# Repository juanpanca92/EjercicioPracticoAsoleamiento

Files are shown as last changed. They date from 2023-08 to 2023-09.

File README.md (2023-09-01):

# EjercicioPracticoAsoleamiento
Ejercicio académico de exploración sobre el asoleamiento en arquitectura a partir de un modelo físico que recrea un heliodon y permite realizar estudios de asoleamiento para diferentes latitudes.

Los documentos son libres y suceptibles de mejora.
Es una propouesta metodológica para el aprendizaje de la mecánica solar y su relación con el ejercicio proytectual en arquitectura.

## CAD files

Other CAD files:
Bioclimática_Despiece Modelo Casa Poli.dwg
Bioclimática_Despiece Heliodon.dwg

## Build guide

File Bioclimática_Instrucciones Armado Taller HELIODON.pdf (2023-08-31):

# Taller Heliodón

## Bioclimática

Instrucciones de armado

Maqueta de estudio Casa Poli | Heliodón
https://www.linkedin.com/in/pan92/ | Juan Paniagua Carvajal

## Plataforma

# Heliodón 1

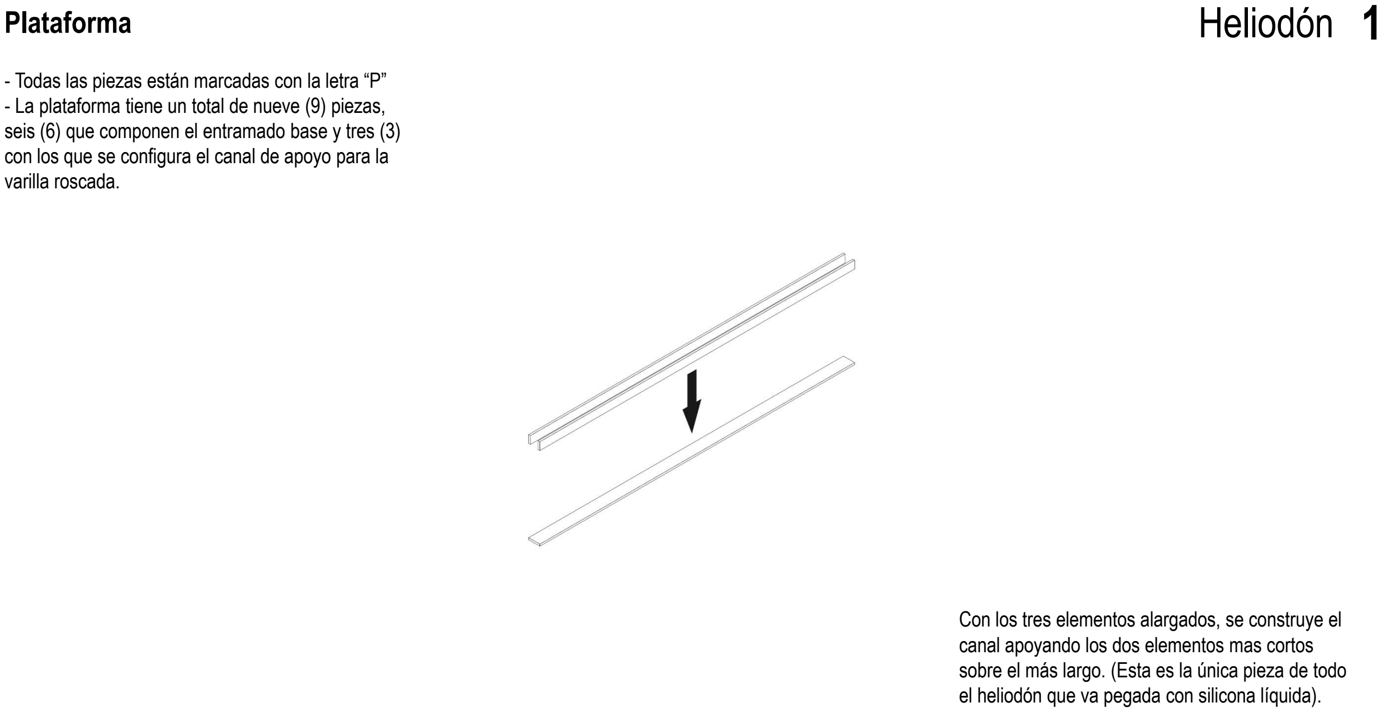
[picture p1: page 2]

- Todas las piezas están marcadas con la letra “P”
- La plataforma tiene un total de nueve (9) piezas, seis (6) que componen el entramado base y tres (3) con los que se configura el canal de apoyo para la varilla roscada.

Con los tres elementos alargados, se construye el canal apoyando los dos elementos mas cortos sobre el más largo. (Esta es la única pieza de todo el heliodón que va pegada con silicona líquida).

## Plataforma

# Heliodón 2

- Todas las piezas están marcadas con la letra “P”
- La plataforma tiene un total de nueve (9) piezas, seis (6) que componen el entramado base y tres (3) con los que se configura el canal de apoyo para la varilla roscada.

El elemento debe quedar de esta forma

## Plataforma

# Heliodón 3

- Todas las piezas están marcadas con la letra “P”
- La plataforma tiene un total de nueve (9) piezas, seis (6) que componen el entramado base y tres (3) con los que se configura el canal de apoyo para la varilla roscada.

Las piezas se ensamblan de forma machimbrada como lo indica la imagen.
Hay tres de las piezas que tienen un canal en la parte superior; sobre este canal se apoya el elemento construido en el paso anterior

Plataforma | 4

# Heliodón

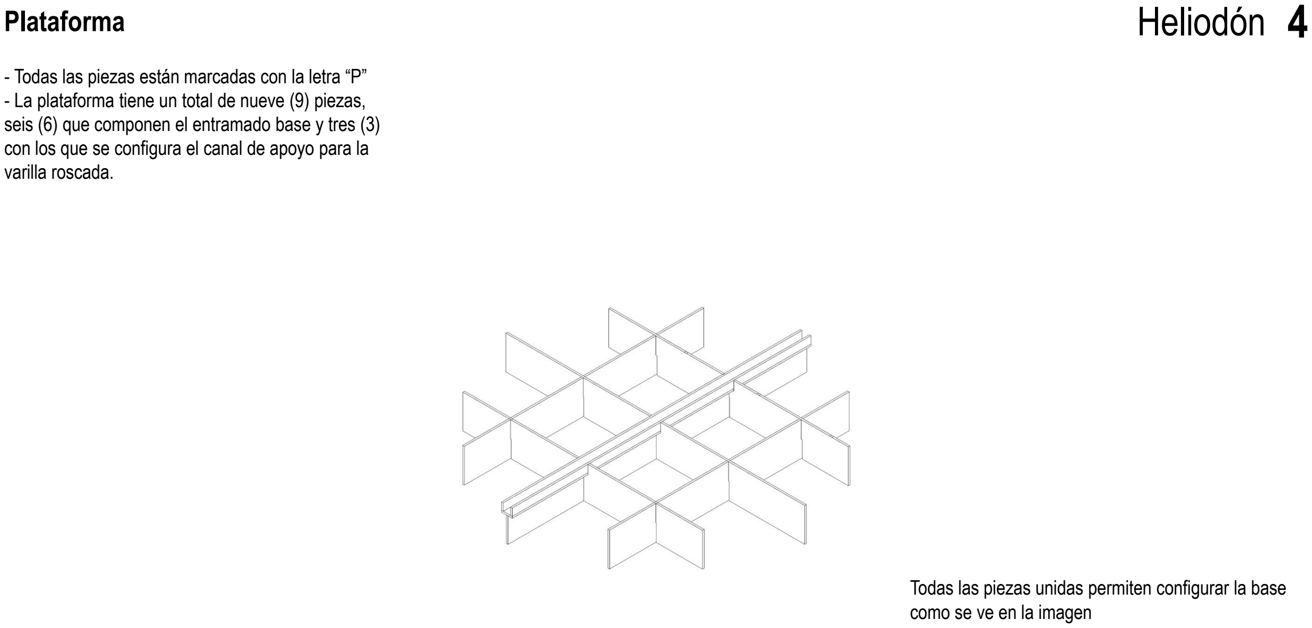
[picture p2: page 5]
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

Todas las piezas unidas permiten configurar la base como se ve en la imagen

Plataforma | 5

# Heliodón

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

Se coloca la varilla roscada de 70cm de largo sobre la plataforma

Plataforma | 6

# Heliodón

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

Por el momento la varilla solo se apoya sobre la plataforma.

Base | 7

# Heliodón

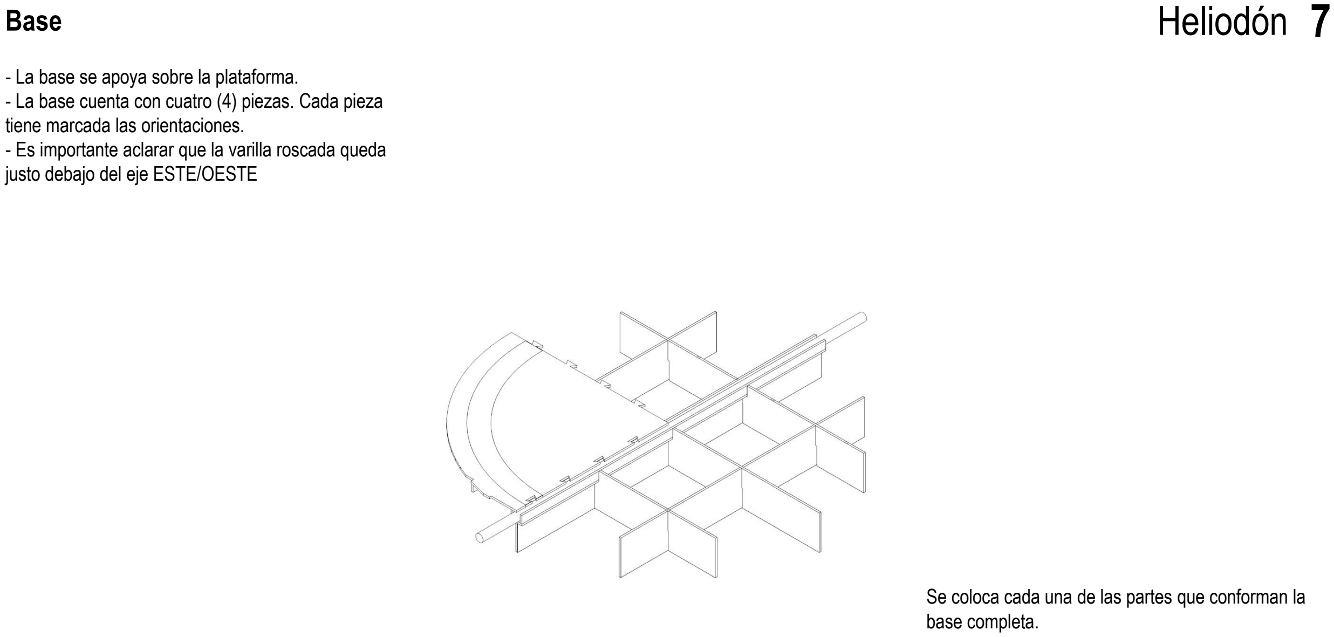
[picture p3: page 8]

- La base se apoya sobre la plataforma.
- La base cuenta con cuatro (4) piezas. Cada pieza tiene marcada las orientaciones.
- Es importante aclarar que la varilla roscada queda justo debajo del eje ESTE/OESTE

Se coloca cada una de las partes que conforman la base completa.

Base | 8

# Heliodón

- La base se apoya sobre la plataforma.
- La base cuenta con cuatro (4) piezas. Cada pieza tiene marcada las orientaciones.
- Es importante aclarar que la varilla roscada queda justo debajo del eje ESTE/OESTE

Se coloca cada una de las partes que conforman la base completa.

Base | 9

# Heliodón

- La base se apoya sobre la plataforma.
- La base cuenta con cuatro (4) piezas. Cada pieza tiene marcada las orientaciones.
- Es importante aclarar que la varilla roscada queda justo debajo del eje ESTE/OESTE

Se coloca cada una de las partes que conforman la base completa.

Base | 10

# Heliodón

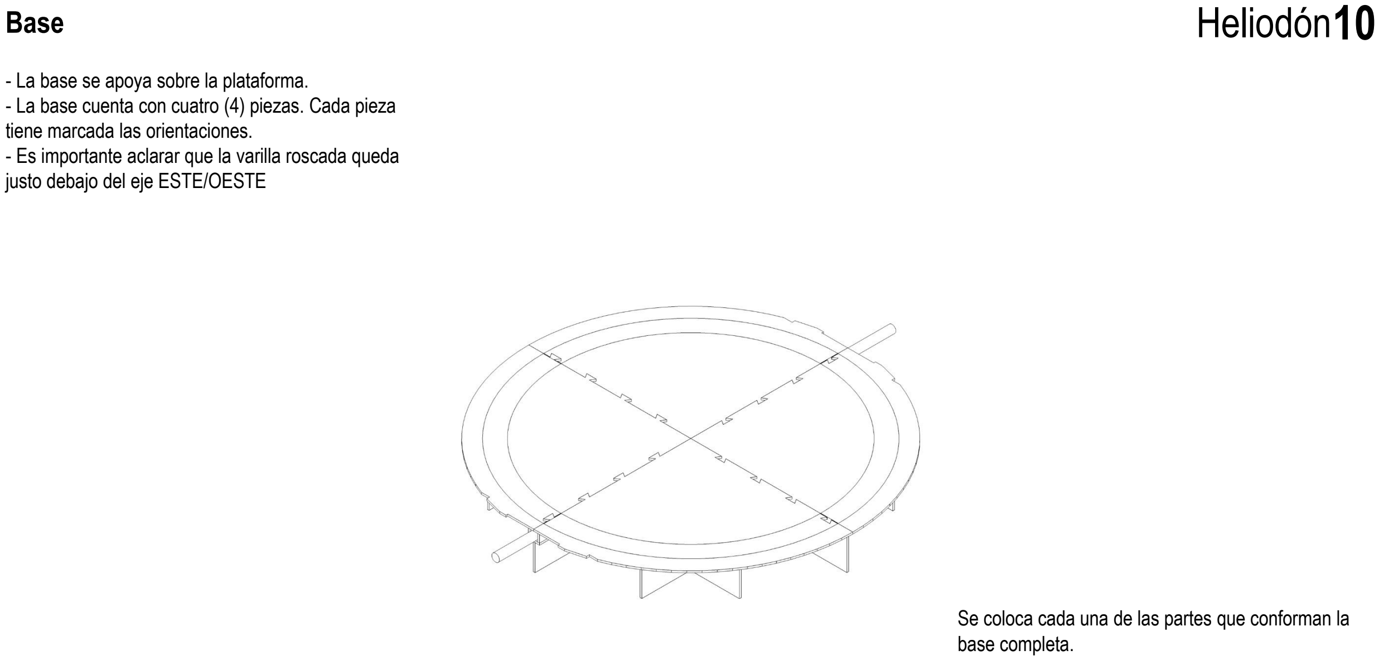
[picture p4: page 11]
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

Se coloca cada una de las partes que conforman la base completa.

Guías latitud | 11

# Heliodón

- Teniendo la varilla como guía y la base ubicada, los dos discos guías de la latitud encajan en los extremos ESTE y OESTE del heliodón.
- El encaje de estas piezas, asegura tanto la plataforma como la base.
- NOTA: No se deben poner las tuercas aún.

Cómo se indica en la imagen, los discos encajan en la varilla. La línea guía marcada en cada disco debe ir hacía el exterior del heliodón y ubicada en la parte superior del disco.

Guías latitud | 12

# Heliodón

- Teniendo la varilla como guía y la base ubicada, los dos discos guías de la latitud encajan en los extremos ESTE y OESTE del heliodón.
- El encaje de estas piezas, asegura tanto la plataforma como la base.
- NOTA: No se deben poner las tuercas aún.

Una vez encajadas las piezas, el heliodón se debe ver de esta manera

Soportes bóveda | 13
- Son dos soportes en total, cada uno esta marcado
en sus diferentes piezas como “A” y “B”.
- Cada uno de los soportes se construye con un total de cinco (5) piezas.
- De las piezas que se resaltan en rojo, hay una por soporte que cuenta con tres (3) letras adicionales marcadas: “J” – “S” – “D”. Esta pieza debe ir en la parte superior
- Estas letras corresponden a los meses de las fechas representativas del calendario solar, y son la guía para los elementos de la bóveda.
- Cada uno de los soportes se debe ubicar en el heliodón siguiendo la lógica de la mecánica solar. La letra “J” correspondiente al mes de Junio debe ir hacía el norte.

Las piezas encajan entre ellas como se indica en la imagen.

# Heliodón

Soportes bóveda | 14

Una vez se tenga el soporte armando es encajado a través de la varilla roscada en el resto del heliodón.
NOTA: Se recuerda la importancia de ubicar el soporte según las letras guías y el norte del heliodón.
- Son dos soportes en total, cada uno esta marcado en sus diferentes piezas como “A” y “B”.
- Cada uno de los soportes se construye con un total de cinco (5) piezas.
- De las piezas que se resaltan en rojo, hay una por soporte que cuenta con tres (3) letras adicionales marcadas: “J” – “S” – “D”. Esta pieza debe ir en la parte superior
- Estas letras corresponden a los meses de las fechas representativas del calendario solar, y son la guía para los elementos de la bóveda.
- Cada uno de los soportes se debe ubicar en el heliodón siguiendo la lógica de la mecánica solar. La letra “J” correspondiente al mes de Junio debe ir hacía el norte.

# Heliodón

Soportes bóveda | 15

# Heliodón

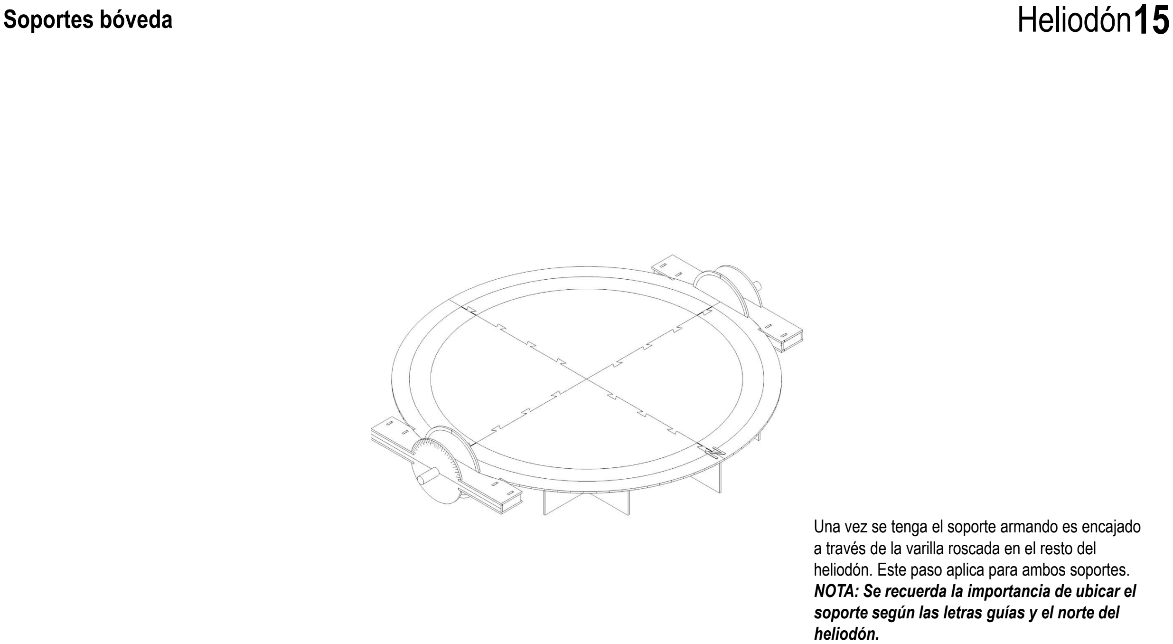
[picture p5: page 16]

Una vez se tenga el soporte armando es encajado a través de la varilla roscada en el resto del heliodón. Este paso aplica para ambos soportes. NOTA: Se recuerda la importancia de ubicar el soporte según las letras guías y el norte del heliodón.

Ajuste soportes | 16

# Heliodón

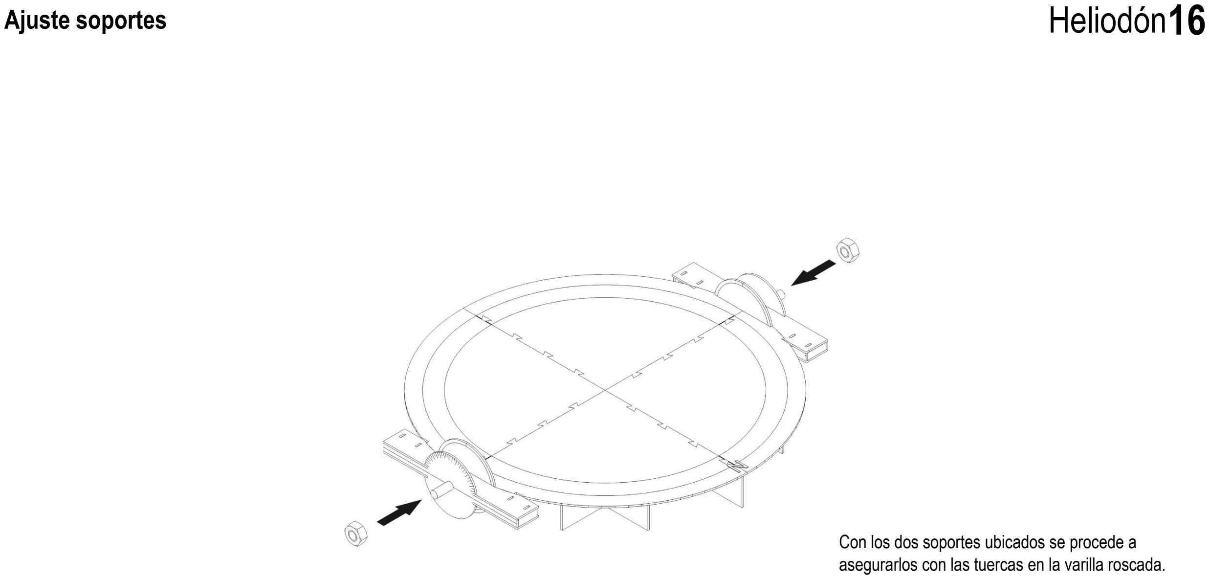
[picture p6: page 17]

Con los dos soportes ubicados se procede a asegurarlos con las tuercas en la varilla roscada.

Disposición bóveda | 17

# Heliodón

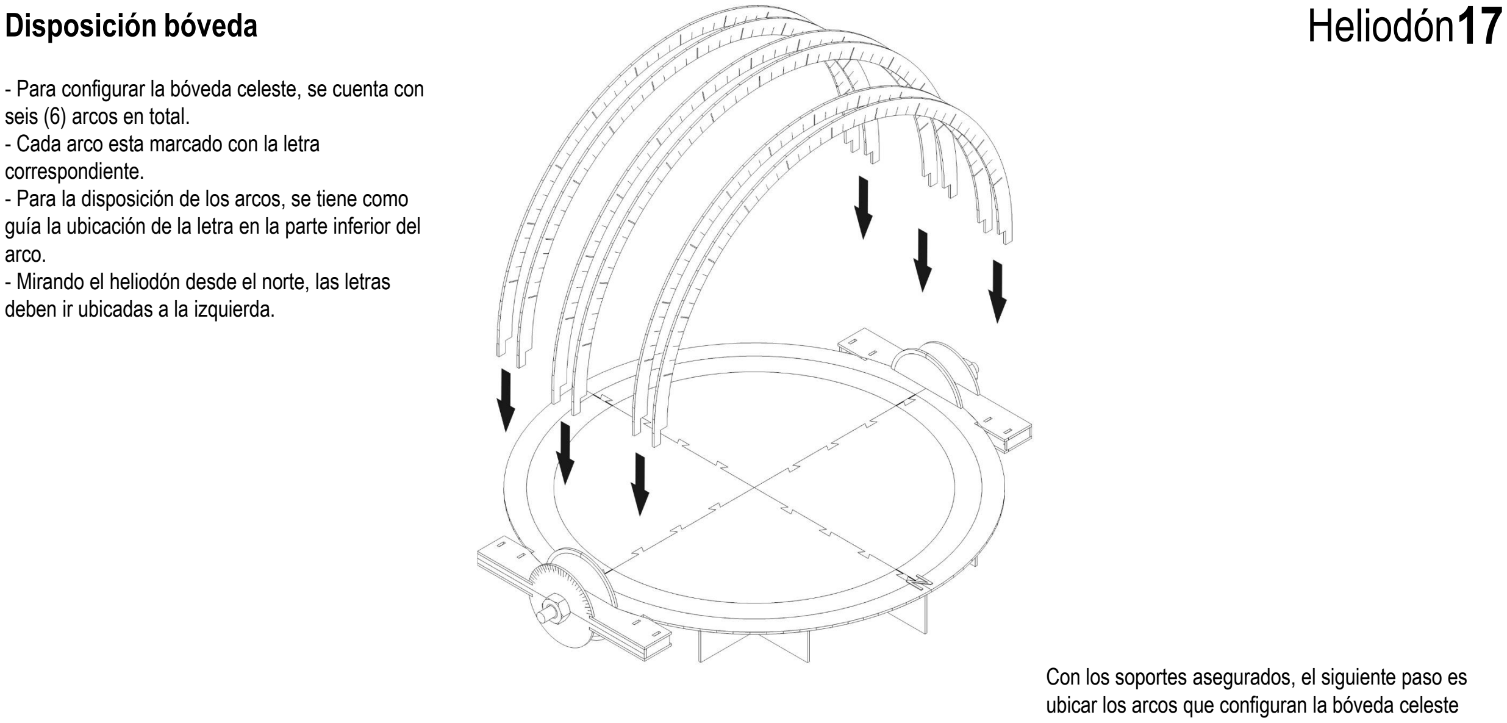
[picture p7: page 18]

Con los soportes asegurados, el siguiente paso es ubicar los arcos que configuran la bóveda celeste

- Para configurar la bóveda celeste, se cuenta con seis (6) arcos en total.
- Cada arco esta marcado con la letra correspondiente.
- Para la disposición de los arcos, se tiene como guía la ubicación de la letra en la parte inferior del arco.
- Mirando el heliodón desde el norte, las letras deben ir ubicadas a la izquierda.

Disposición bóveda | 18

# Heliodón

Al ubicar cada uno de los arcos en su ranura correspondiente, el heliodón se debe ver como en la imagen.

Soportes luz/sol – Guías horas | 19

# Heliodón

Los soportes de luz número 1 y 3 están constituidos por seis (6 piezas).
El soporte de luz número 2 esta constituido por cinco (5) piezas .
Cada soporte de luz encaja de forma machimbrada.
- El heliodón cuenta con tres (3) de estos soportes, los cuales se disponen en las tres parejas de arcos correspondientes a los diferentes meses.
- Los soportes de luz están marcados con los números 1,2 y 3. El número 2 corresponde a la letra “S”, los números 1 y 3 a las letras “J” y “D”.

Soportes luz/sol – Guías horas | 20

# Heliodón

Los soportes de luz número 1 y 3 están constituidos por seis (6 piezas).
El soporte de luz número 2 esta constituido por cinco (5) piezas .
Cada soporte de luz encaja de forma machimbrada.
- El heliodón cuenta con tres (3) de estos soportes, los cuales se disponen en las tres parejas de arcos correspondientes a los diferentes meses.
- Los soportes de luz están marcados con los números 1,2 y 3. El número 2 corresponde a la letra “S”, los números 1 y 3 a las letras “J” y “D”.

Soportes luz/sol – Guías horas | 21

# Heliodón

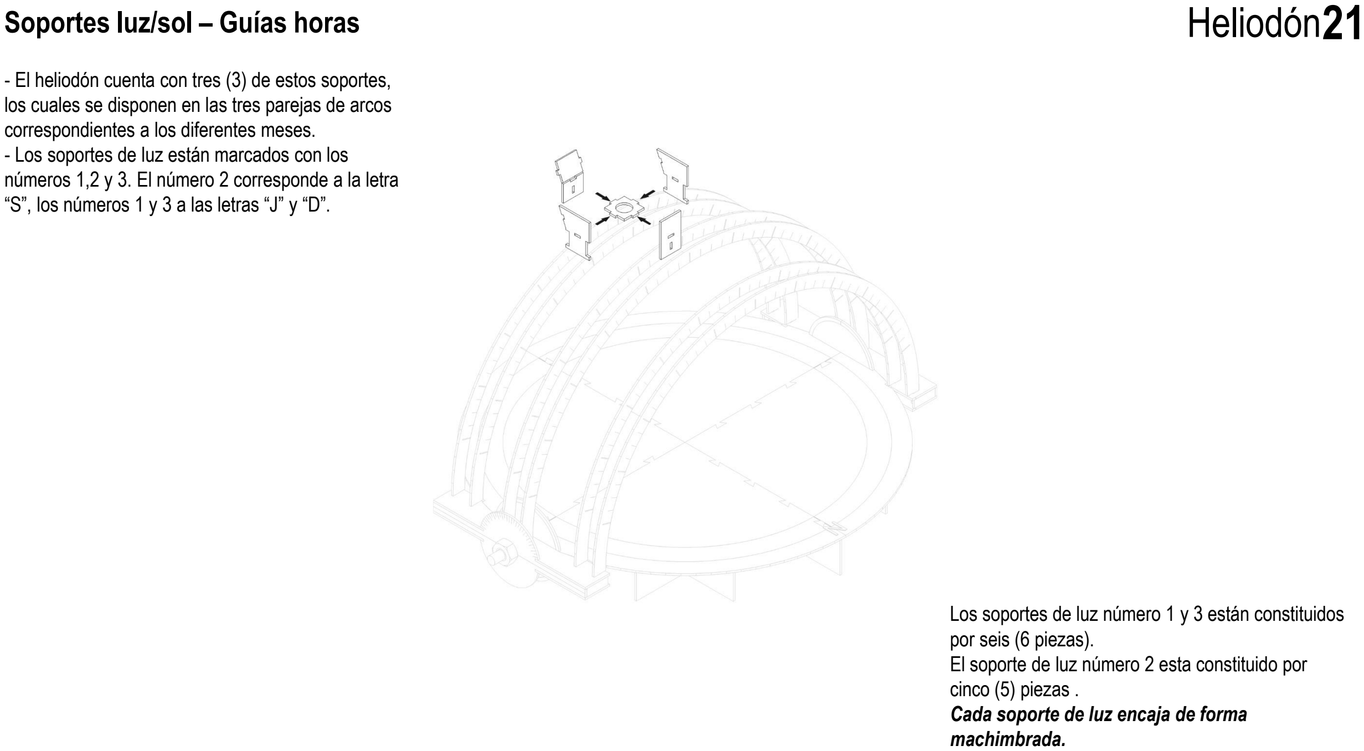
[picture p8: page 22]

Los soportes de luz número 1 y 3 están constituidos por seis (6 piezas).
El soporte de luz número 2 esta constituido por cinco (5) piezas .
Cada soporte de luz encaja de forma machimbrada.
- El heliodón cuenta con tres (3) de estos soportes, los cuales se disponen en las tres parejas de arcos correspondientes a los diferentes meses.
- Los soportes de luz están marcados con los números 1,2 y 3. El número 2 corresponde a la letra “S”, los números 1 y 3 a las letras “J” y “D”.

Heliodón armado | 22

# Heliodón

Una vez ubicados los soportes de luz, el heliodón ha sido construido y ensamblado en su totalidad, se debe ver como en la imagen.

- Con todas las piezas ensambladas el heliodón esta completo; el siguiente paso es ubicar la linterna en el soporte de luz según la fecha y hora que se quiere evaluar.

Organización fichas | 23 - | El despiece entregado contiene una

numeración para cada una de las fichas, se
recomienda despegar cuidadosamente la cinta de enmascarar e identificar las fichas que tienen un número o una letra (en el caso del terreno). Hay fichas que se repiten hasta

3
veces es importante agruparlas todas.

NOTA: La maqueta de estudio se compone de tres materiales, cartón paja para el terreno y la base, cartón caja 2mm para muros interiores y fachadas y cartón caja 4mm para recrear los volúmenes perimetrales. (las siguientes imágenes muestran número por número dónde va la ficha)

# Maqueta de estudio

Armado | 24

# Maqueta de estudio

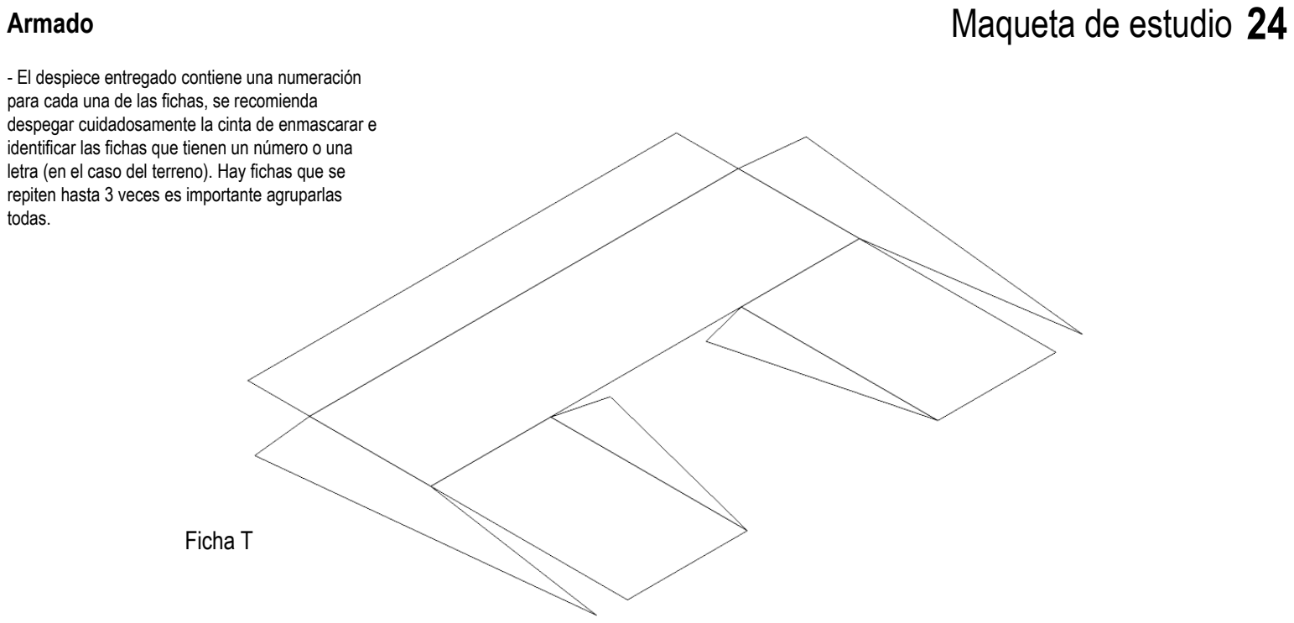
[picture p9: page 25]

- El despiece entregado contiene una numeración para cada una de las fichas, se recomienda despegar cuidadosamente la cinta de enmascarar e identificar las fichas que tienen un número o una letra (en el caso del terreno). Hay fichas que se repiten hasta 3 veces es importante agruparlas todas.

## Ficha T

Armado | 25

# Maqueta de estudio

- El despiece entregado contiene una numeración para cada una de las fichas, se recomienda despegar cuidadosamente la cinta de enmascarar e identificar las fichas que tienen un número o una letra (en el caso del terreno). Hay fichas que se repiten hasta 3 veces es importante agruparlas todas.

## Ficha T

Armado | Maqueta de estudio 26

## Ficha 1 y 2

Armado | Maqueta de estudio 27

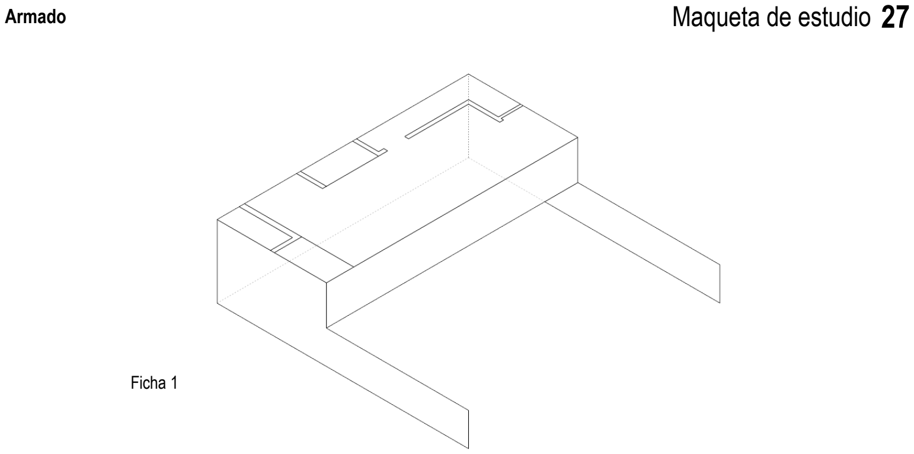
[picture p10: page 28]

## Ficha 1

Armado | Maqueta de estudio 28

## Ficha 2

Armado | Maqueta de estudio 29

## Ficha 1 y 2

Armado | Maqueta de estudio 30

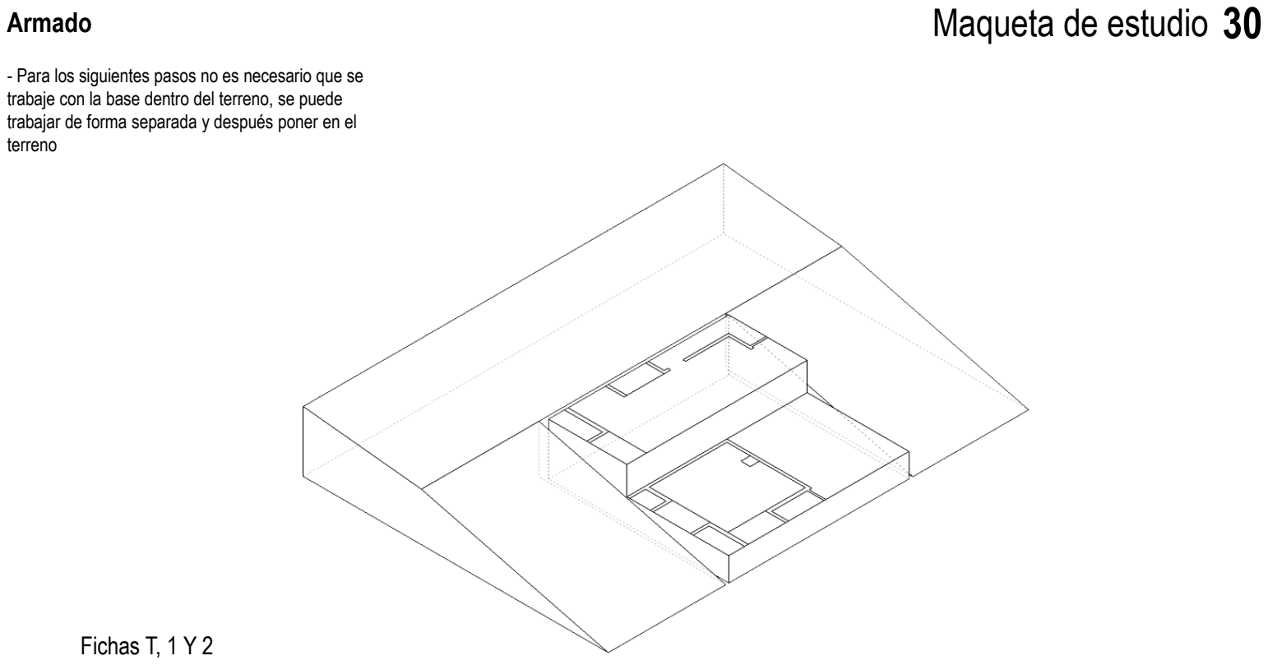
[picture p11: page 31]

## Fichas T, 1 Y 2

- Para los siguientes pasos no es necesario que se trabaje con la base dentro del terreno, se puede trabajar de forma separada y después poner en el terreno

Armado | Maqueta de estudio 31

## Ficha 3 (una está en caja 4mm y otra en caja 2mm)

- Se debe poner la ficha más delgada en la parte superior para que les puedan servir las guías que están marcadas

Armado | Maqueta de estudio 32

## Ficha 3 (una está en caja 4mm y otra en caja 2mm)

- Se debe poner la ficha más delgada en la parte superior para que les puedan servir las guías que están marcadas

Armado | Maqueta de estudio 33

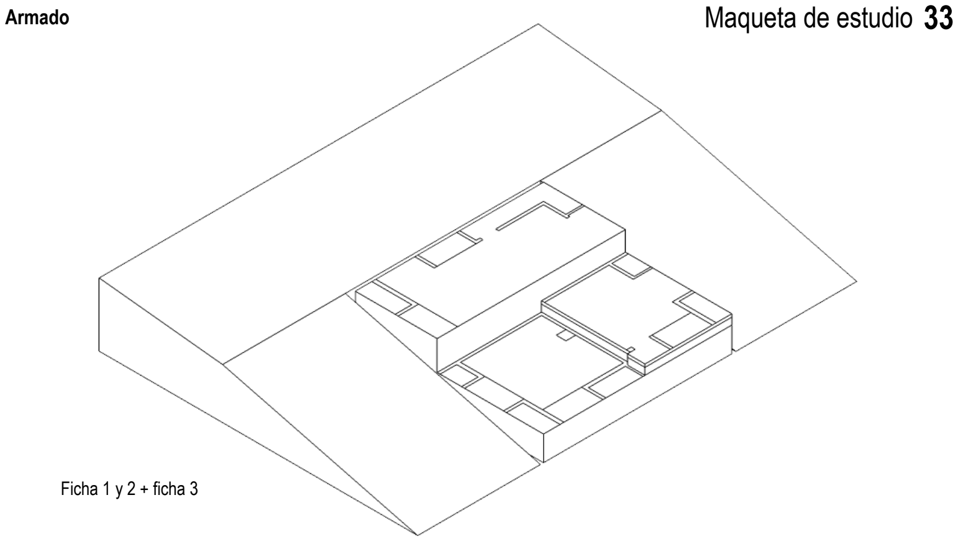
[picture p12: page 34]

## Ficha 1 y 2 + ficha 3

Armado | Maqueta de estudio 34

## Ficha 4

Armado | Maqueta de estudio 35

## Ficha 4

Armado | Maqueta de estudio 36

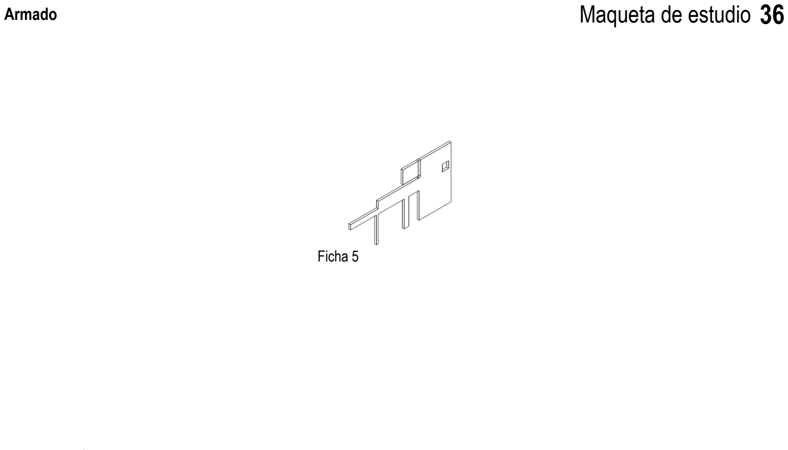
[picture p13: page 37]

## Ficha 5

Armado | Maqueta de estudio 37

## Ficha 5

Armado | Maqueta de estudio 38

## Ficha 5

Armado | Maqueta de estudio 39

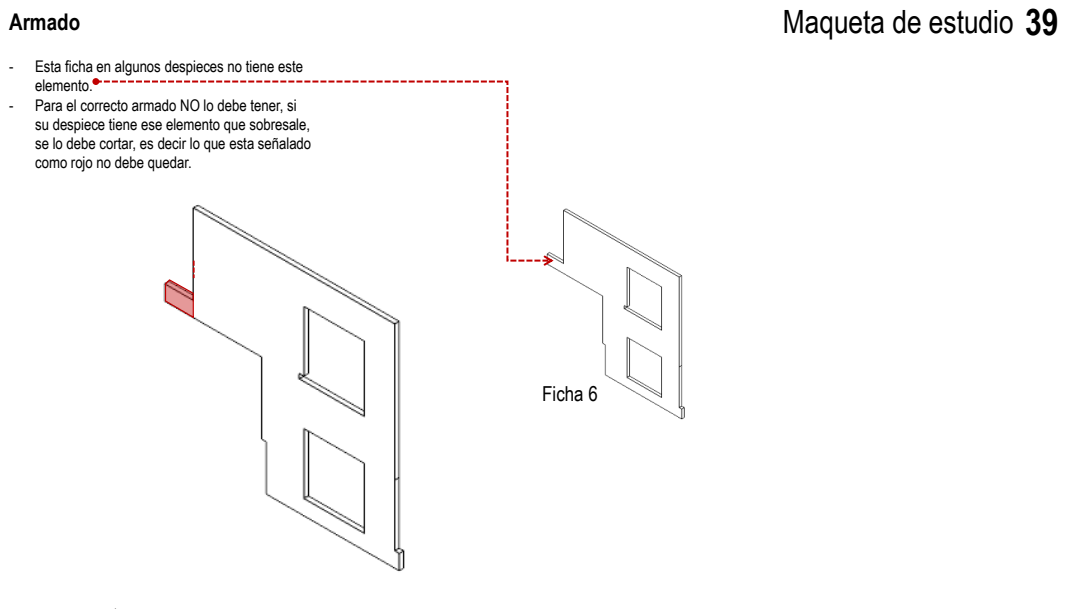
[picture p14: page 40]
Ficha 6

- Esta ficha en algunos despieces no tiene este
elemento.
- Para el correcto armado NO lo debe tener, si
su despiece tiene ese elemento que sobresale,
se lo debe cortar, es decir lo que esta señalado
como rojo no debe quedar.

Armado | Maqueta de estudio 40

## Ficha 6

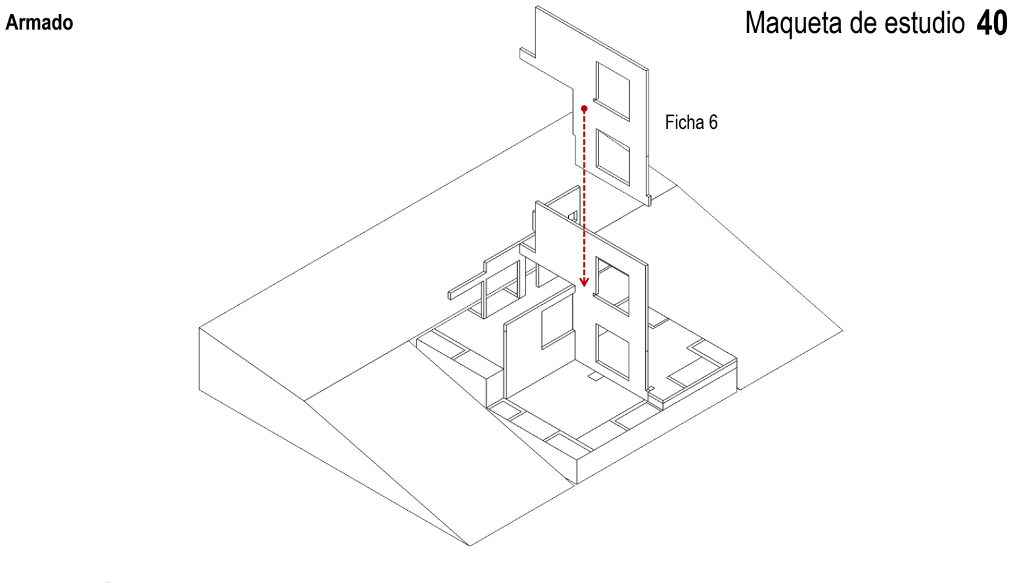
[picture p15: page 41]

Armado | Maqueta de estudio 41

## Ficha 7

Armado | Maqueta de estudio 42

## Ficha 7

Armado | Maqueta de estudio 43

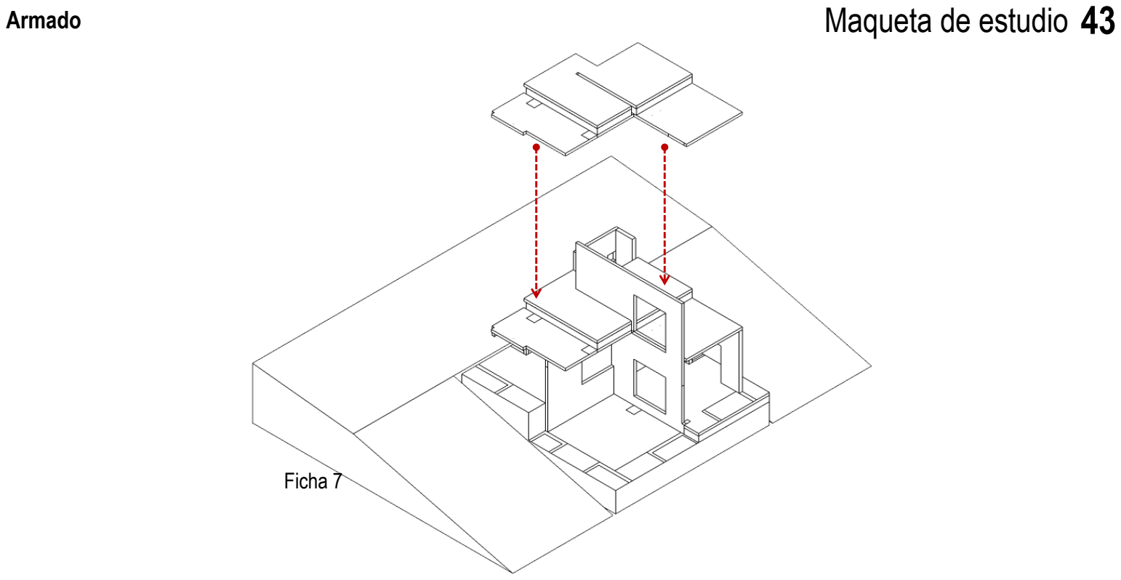
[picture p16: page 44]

## Ficha 7

Armado | Maqueta de estudio 44

## Ficha 8

Armado | Maqueta de estudio 45

## Ficha 8

Armado | Maqueta de estudio 46

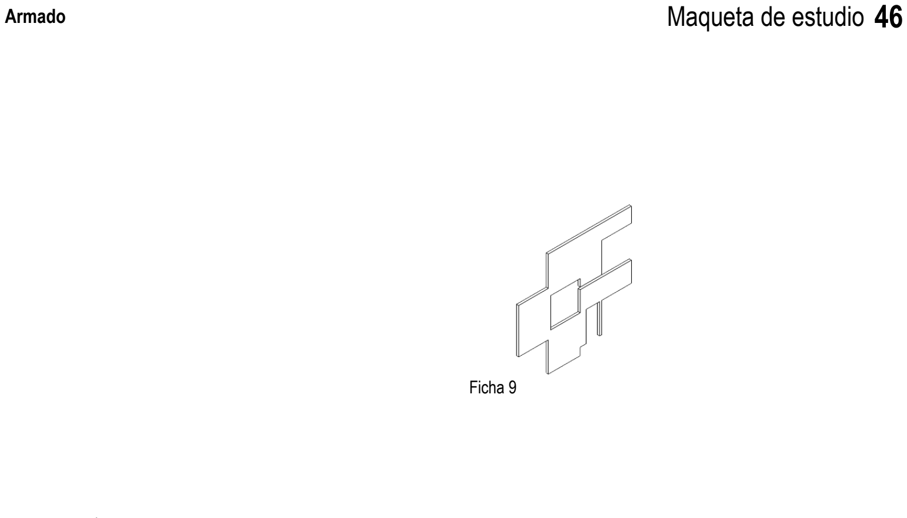
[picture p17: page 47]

## Ficha 9

Armado | Maqueta de estudio 47

## Ficha 9

Armado | Maqueta de estudio 48

## Ficha 10

Armado | Maqueta de estudio 49

## Ficha 10

Armado | Maqueta de estudio 50

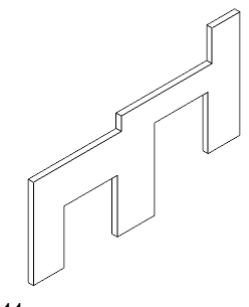
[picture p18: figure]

## Ficha 11

Armado | Maqueta de estudio 51

## Ficha 11

- Es importante que identifiquen que la imagen ya se esta viendo desde otro ángulo, es decir la ficha 11 en la fachada que esta ubicada a la derecha de la ficha 9 (si la estuviera viendo de frente)

Armado | Maqueta de estudio 52

## Ficha 12

Armado | Maqueta de estudio 53

## Ficha 12

Armado | Maqueta de estudio 54

Armado | Maqueta de estudio 55

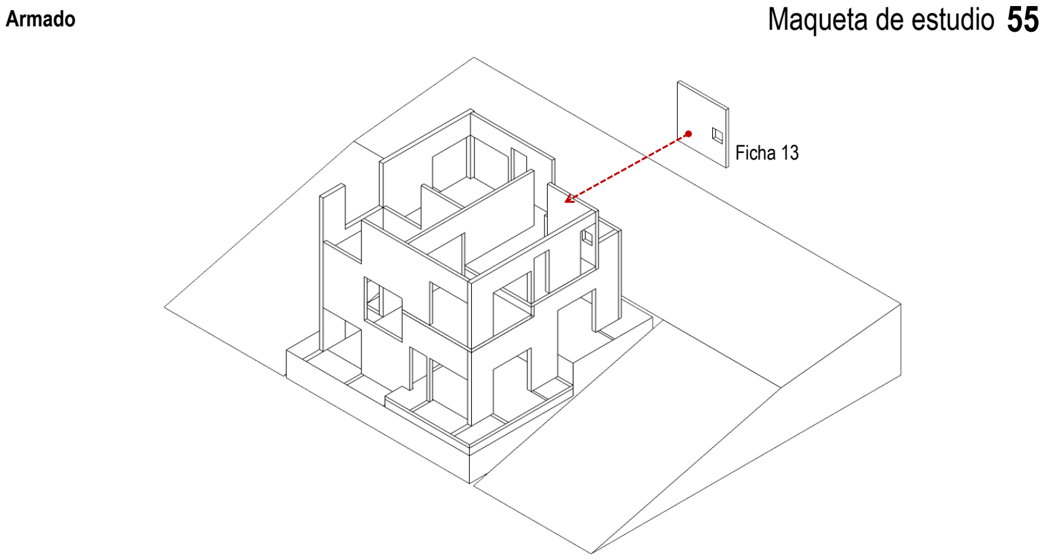
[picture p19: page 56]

## Ficha 13

Armado | Maqueta de estudio 56

Armado | Maqueta de estudio 57

## Ficha 14 - Muro

Armado | Maqueta de estudio 58

## Ficha 14 - Volumen fachada

Armado | Maqueta de estudio 59

## Ficha 14 - Volumen fachada

Armado | Maqueta de estudio 60

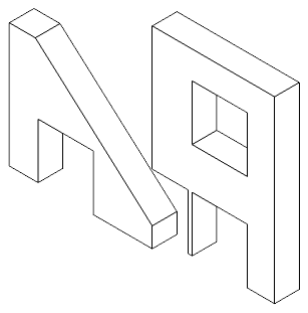
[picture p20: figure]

## Fichas 15

Armado | Maqueta de estudio 61

## Fichas 15

Armado | Maqueta de estudio 62
- Es importante que identifiquen que la imagen ya
se esta viendo desde otro ángulo, es decir la ficha
16 en la fachada que esta ubicada a la izquierda de la ficha 9 (si la estuviera viendo de frente)

Armado | Maqueta de estudio 63

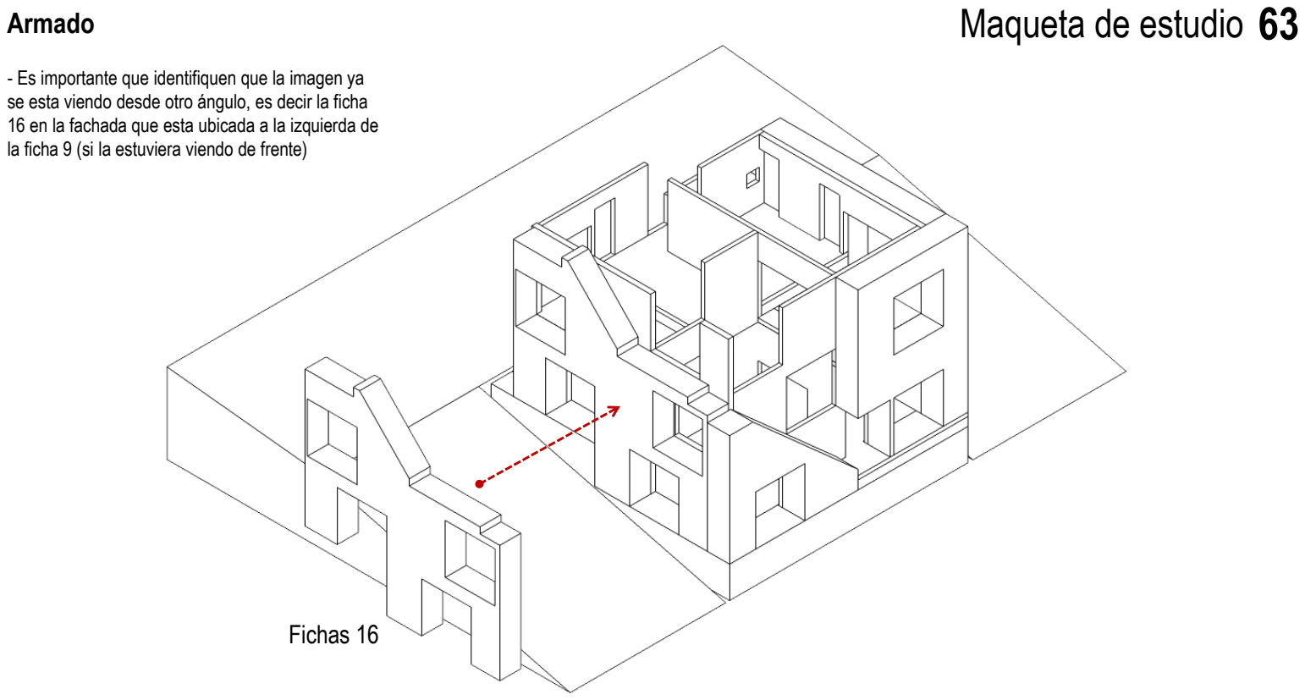
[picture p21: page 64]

## Fichas 16

- Es importante que identifiquen que la imagen ya se esta viendo desde otro ángulo, es decir la ficha 16 en la fachada que esta ubicada a la izquierda de la ficha 9 (si la estuviera viendo de frente)

Armado | Maqueta de estudio 64

## Fichas 17

- Es importante que identifiquen que la imagen ya
se esta viendo desde otro ángulo, es decir la ficha
17 en la fachada que esta ubicada en la parte posterior de la ficha 9 (si la estuviera viendo de frente)

Armado | Maqueta de estudio 65

## Fichas 17

- Es importante que identifiquen que la imagen ya se esta viendo desde otro ángulo, es decir la ficha 17 en la fachada que esta ubicada en la parte posterior de la ficha 9 (si la estuviera viendo de frente)

Armado fachadas | Maqueta de estudio 66
19

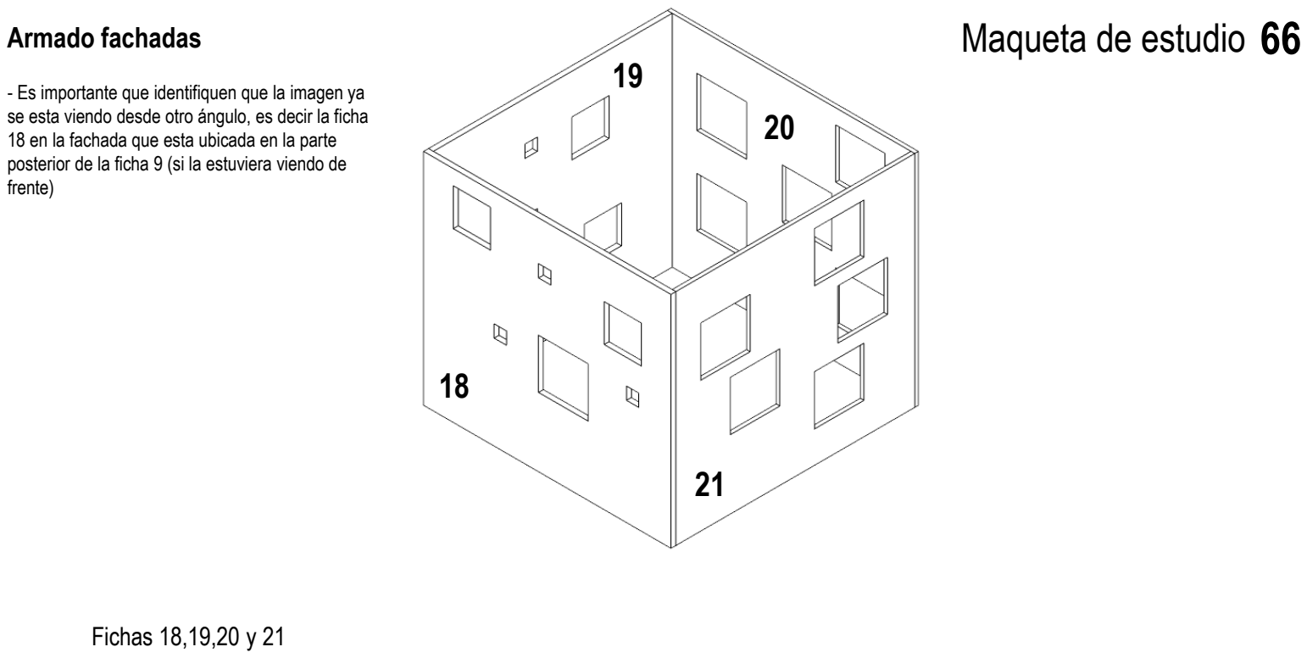
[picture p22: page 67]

## Fichas 18,19,20 y 21

- Es importante que identifiquen que la imagen ya se esta viendo desde otro ángulo, es decir la ficha 18 en la fachada que esta ubicada en la parte posterior de la ficha 9 (si la estuviera viendo de frente)

18

20

21

Armado fachadas | Maqueta de estudio 67
19 20

## Fichas 18,19,20 y 21

18
21

Armado Cubierta | Maqueta de estudio 69

## Fichas 22

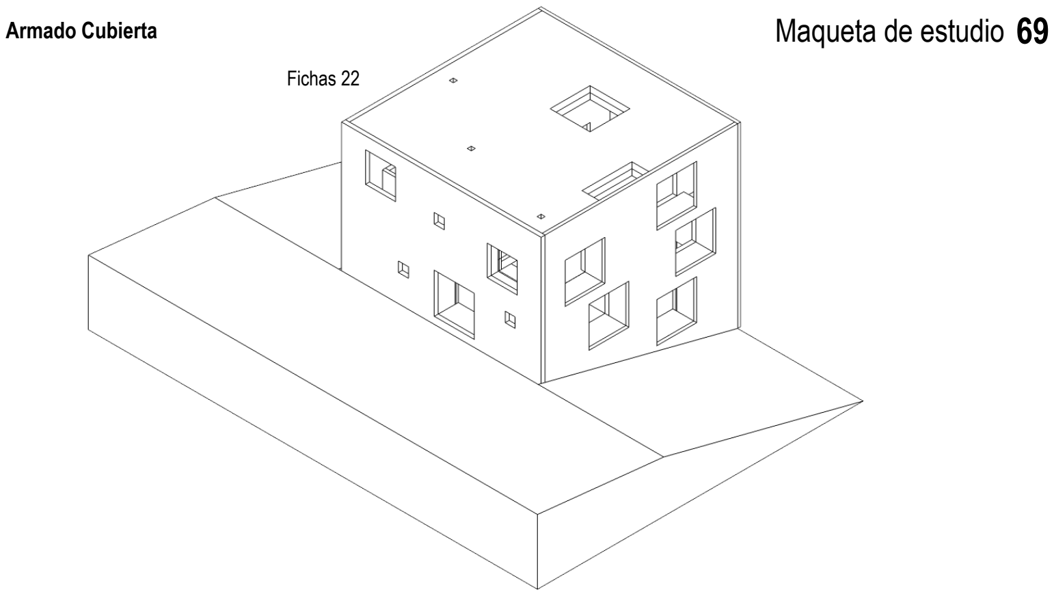
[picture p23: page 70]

Armado Cubierta | Maqueta de estudio 70

## Fichas sin número

Armado Cubierta | Maqueta de estudio 71

Vistas de la maqueta de estudio | Maqueta de estudio 71

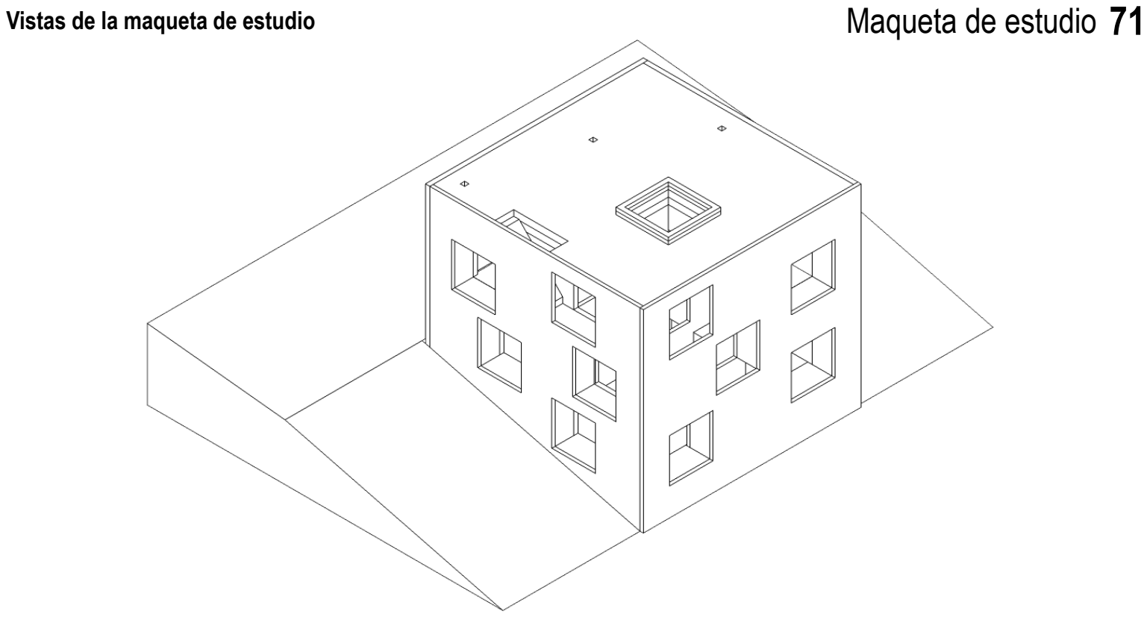
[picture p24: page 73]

Vistas de la maqueta de estudio | Maqueta de estudio 72
